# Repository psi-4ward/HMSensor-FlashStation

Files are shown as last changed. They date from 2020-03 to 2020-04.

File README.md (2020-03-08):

# HMSensor-FlashStation

Hilfsplatine um HMSensor PCBs mit Hilfe von PogoPins einzuspannend und zu flashen.

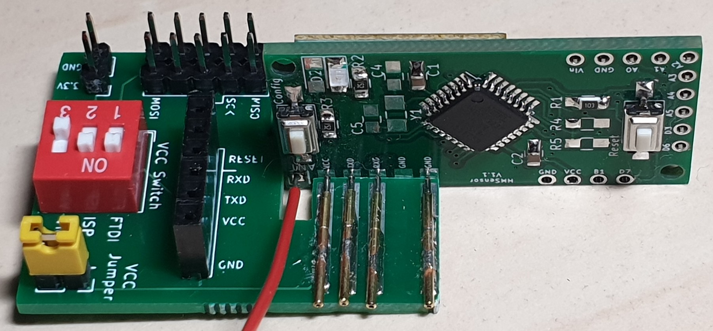
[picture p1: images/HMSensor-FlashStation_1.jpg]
HMSensor-FlashStation


HMSensor versucht eine universelle Hardware-Basis für AskSin++ Sensoren und Aktoren zu sein.

* [HMSensor PCB](https://github.com/pa-pa/HMSensor) from pa-pa
* [HMSensor Documentation](https://asksinpp.de/Projekte/psi/HMSensor/) on asksinpp.de

Auf dem Testaufbau sind **P75-B1 Pogo Pins** verbaut.

## :bangbang::bug: **Fehler in v1.0** :bangbang:

* RX/TX ist _nicht_ gedreht gegenüber dem USB-UART. Entweder FTDI über JumperWire anschließen und RX/TX drehen oder den Fehler mit Draht auf der Platine beheben.
* RESET Kondensator fehlt

=> [v1.0 BugFix Guide](./v1.0-bugfix-guide/README.md)

## Features

* DIP-Schalter um die Versorgungsspannungen zu schalten.
* VCC-Jumper: z.B. um eine Strommessung zwischen zu schalten.
* 5x2 Pin ISP Header, kompatibel mit Diamex oder USBasp
* FTDI Header

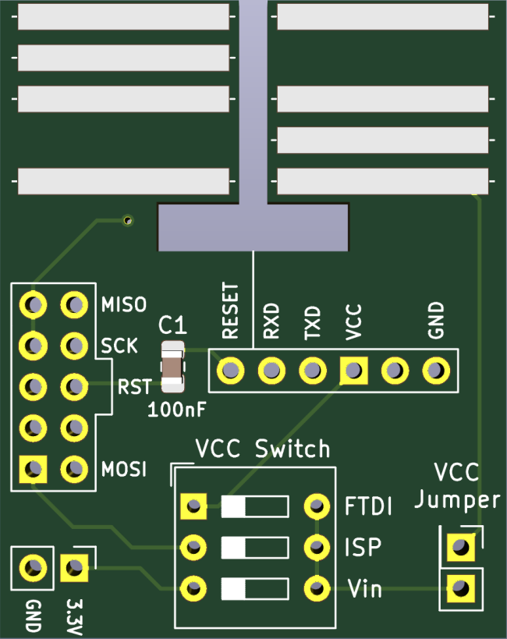
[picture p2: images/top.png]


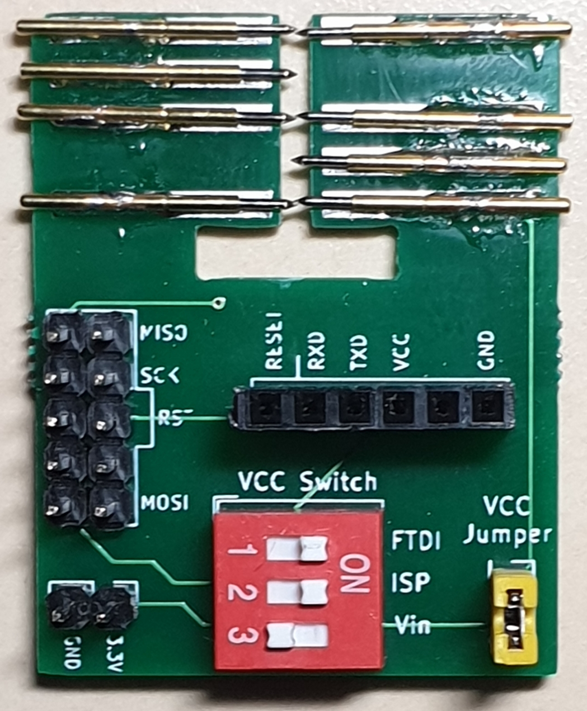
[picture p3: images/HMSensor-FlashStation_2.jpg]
HMSensor-FlashStation


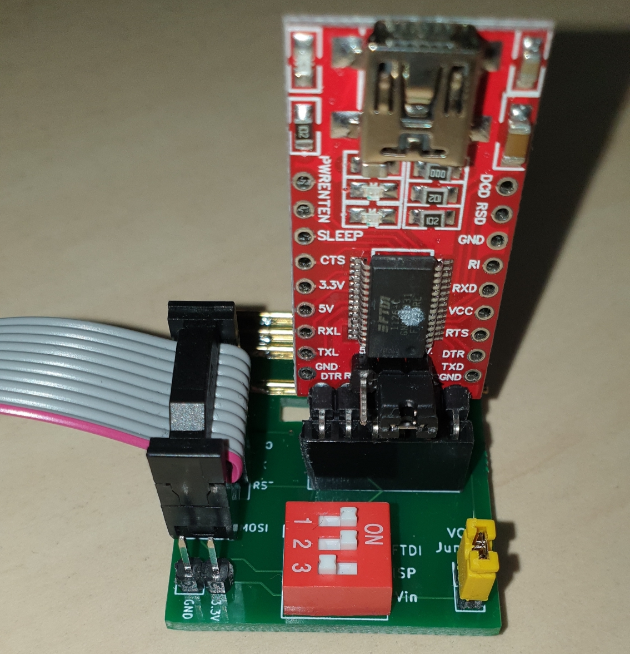
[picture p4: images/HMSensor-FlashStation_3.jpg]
HMSensor-FlashStation


## Changelog / Notes

### v1.1

* Fehler Behoben im PCB-Design: RX/TX ist _nicht_ gedreht gegenüber dem USB-UART
* RESET Kondensator hinzugefügt

## Lizenz

MIT

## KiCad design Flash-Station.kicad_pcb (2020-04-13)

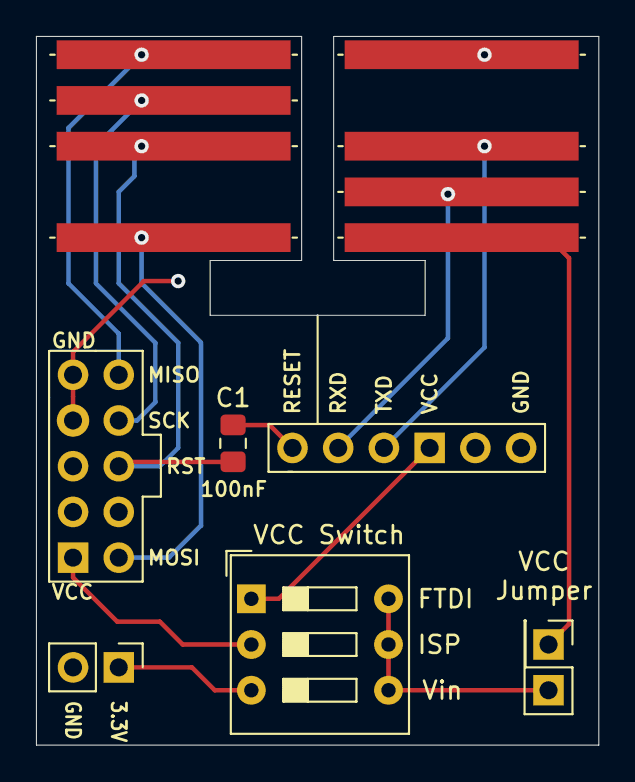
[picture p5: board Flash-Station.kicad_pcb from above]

Board: 2 copper layers, 31.2 x 39.4 mm, 8 parts (0 on the bottom side), 13 nets.

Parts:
C1: 100nF; C_0805_2012Metric_Pad1.15x1.40mm_HandSolder
J1: Vin 3.3V; PinHeader_1x02_P2.54mm_Vertical
J2: FTDI; PinHeader_1x06_P2.54mm_Vertical
J3: ISP; PinHeader_2x05_P2.54mm_Vertical
J4: HMSensor Pogo 2; PogoPad_5x
J5: HMSensor Pogo 1; PogoPad_5x
J6: VCC Jumper; PinHeader_2x01_P2.54mm_Vertical
SW1: VCC Switch; SW_DIP_SPSTx03_Slide_9.78x9.8mm_W7.62mm_P2.54mm

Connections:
GND: J1.2, J2.6, J3.1, J3.3, J4.1
MISO: J3.2, J5.5
MOSI: J3.10, J5.1
unnamed: C1.1, J2.1
unnamed: J1.1, SW1.3
unnamed: J2.4, SW1.1
unnamed: J3.9, SW1.2
unnamed: J4.5, J6.1
RESET: C1.2, J3.6, J5.3
RXD: J2.3, J4.3
SCK: J3.4, J5.4
TXD: J2.2, J4.4
VCC: J6.2, SW1.4, SW1.5, SW1.6

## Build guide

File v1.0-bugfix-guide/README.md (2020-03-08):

# Bugfix Anleitung für v1.0

Die Version 1.0 der Platine enthält leider zwei Fehler welche aber relativ einfach behoben werden können.

Die Leiterbahnen, im Bild markiert mit **X**, müssen unterbrochen werden.

Zwischen RESET des FTDI-Headers und RESET des ISP Headers wird ein 100nF Kondensator in Reihe geschalten.

Die beiden TX / RX Leitungen jeweils vertauscht verbunden.





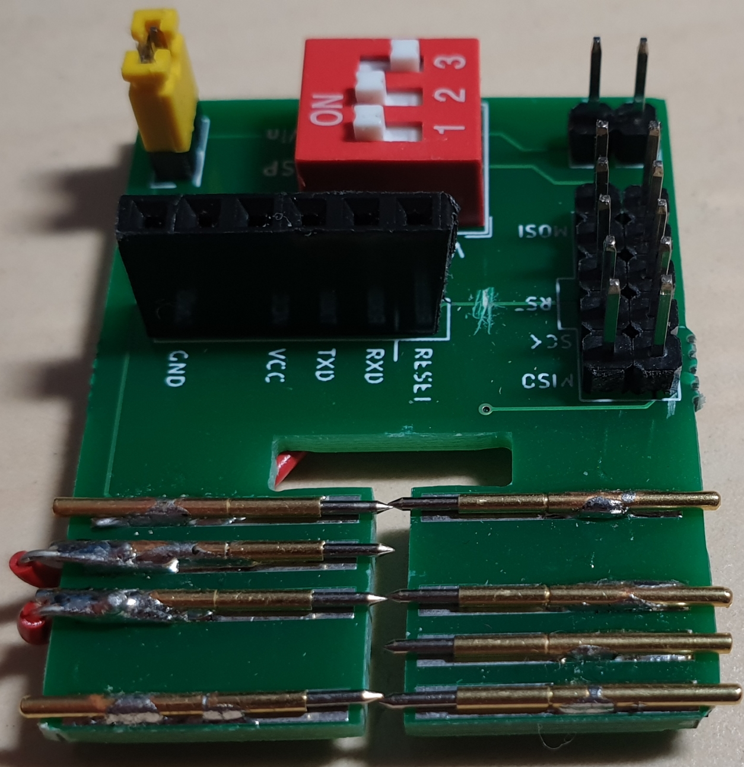
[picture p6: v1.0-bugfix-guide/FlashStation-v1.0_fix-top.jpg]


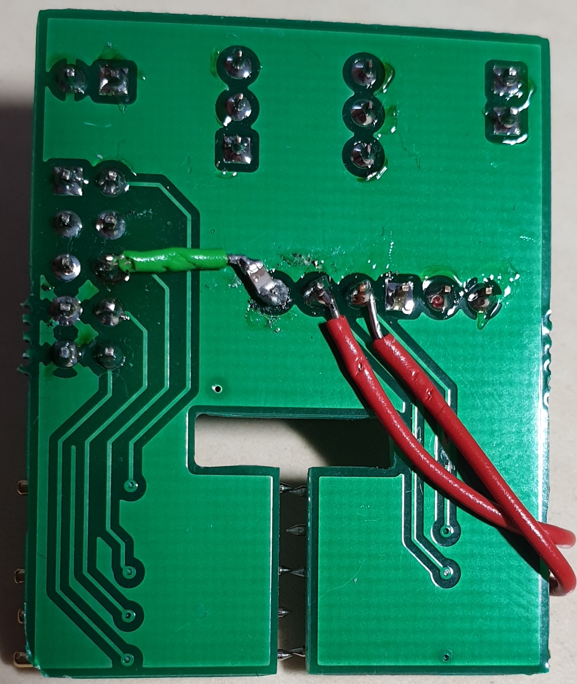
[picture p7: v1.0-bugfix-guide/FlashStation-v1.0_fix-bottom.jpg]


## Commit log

2020-03-08 Fix: Tx/RX interchanged, RESET Kerko
    [Flash-Station-B_Cu.gbl, Flash-Station-B_Mask.gbs, Flash-Station-B_Paste.gbp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]
2020-03-08 Add v1.2 PCB image
2020-03-08 Resize PCB image
2020-03-08 Updated sch
    [Flash-Station.sch]
2020-03-09 Fix Schaltplan
    [Flash-Station.kicad_pcb, Flash-Station.sch]
2020-04-13 Fix gerber
    [Flash-Station-B_Cu.gbl, Flash-Station-B_Cu.gbr, Flash-Station-B_Mask.gbr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]
2020-04-13 Fix plot settings
    [Flash-Station.kicad_pcb]
